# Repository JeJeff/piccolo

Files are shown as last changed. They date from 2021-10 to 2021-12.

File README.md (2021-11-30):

# Piccolo Macropads
These are mini macropads intended for video conference control.  Setup by default for Zoom, it could be used to Teams, Webex, or any other video conference system (or anything else) with keyboard shortcuts just by changing the keymapping.

The [Piccolo Macropad](https://github.com/JeJeff/piccolo/tree/main/piccolo) has 5 buttons, or 4 buttons and a rotary encoder, and an OLED screen.

The [Piccolo Mini Macropad](https://github.com/JeJeff/piccolo/tree/main/piccolo-mini) is the same but without the screen.

## Current Status
### Piccolo
The Piccolo has a working prototype, and revision 2 (including FR4 switch- and back-plates) is ready for ordering.

### Piccolo Mini
The Piccolo mini is designed not yet prototyped.  Work on this is paused until the bigger brother is ready for release.

## License
<br />The Piccolo Macropad and Piccolo Mini Macropad are licensed under a <a rel="license" href="http://creativecommons.org/licenses/by-sa/4.0/">Creative Commons Attribution-ShareAlike 4.0 International License</a>.

If you have built upon this work and have changed the design in a significant way, the non-commercial clause can be waived. If you have developed your own design using files in this repository and would like to sell it, please [create an issue](https://github.com/JeJeff/piccolo/issues/new/choose) to discuss it.

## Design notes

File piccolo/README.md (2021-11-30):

# Piccolo Macropad controller
Piccolo Macropad is intended for video conference control.  Setup by default for Zoom, it could be used to Teams, Webex, or anything else with keyboard shortcuts just by changing the keymapping.

## Key features
* 5 key macro pad
* Both 3 and 5 pin MX style switches supported
* Hot swap sockets
* OLED screen
* Optional rotary encoder replacing one of the keys
* QMK controlled
* Easy to solder

## Additional information
 * 2 layer PCB
 * Switchplate and backplate designs available
 * Both throughhole and SMD diodes supported
 
## Bill of materials
|Reference | Item | Quantity | Notes
|:---:|---|:---:|---
| | **Plates** | |
| | PCB | 1 |
| | Switchplate | 1 | 
| | Backplate | 1 | 
| | | |
| | **Components to solder** | |
| MX1-MX5  | Hotswap sockets | 4-5 | 
| ENC1 | EC11 Rotary Encoder | 0-1 | Optional, replaces MX5.
| D1-D5 | 1N4148 Diode | 5 | Both SMD (SOD-123) and through hole (DO-35) supported.
| U1 | Pro Micro | 1 | Or pin compatible controller.
| U1 | 12x1 male pin header | 2 | For the pro micro.
| OLED1 | 0.91" OLED screen | 1 | If you don't want the screen, consider using the [Piccolo Mini](https://github.com/JeJeff/piccolo/tree/main/piccolo-mini) instead.
| OLED1 | 4x1 male pin header | 1 | For the OLED screen.
| | | |
| | **Hardware** | |
| | M2 standoff 12mm | 3 | Max diameter 3.7mm, required when using back- and switch-plates.
| | M2 x 6mm flat head screw | 6 | Button head screws also work, could go as short as 4mm.
| | Rubber feet 8mm | 4 | 
| | | |
| | **Keys and Knobs** | |
| | MX Switches | 4-5 | 
| | Keycaps | 4-5 | Relegendable caps recommended, but the choice is yours
| | Encoder knob | 0-1 | Matching the encoder, max diameter 18mm

## License
<br />The Piccolo Macropad and Piccolo Mini Macropad are licensed under a <a rel="license" href="http://creativecommons.org/licenses/by-sa/4.0/">Creative Commons Attribution-ShareAlike 4.0 International License</a>.

If you have built upon this work and have changed the design in a significant way, the non-commercial clause can be waived. If you have developed your own design using files in this repository and would like to sell it, please [create an issue](https://github.com/JeJeff/piccolo/issues/new/choose) to discuss it.  I fully support those looking to make new things and be creative and will more than likely approve and support your project.

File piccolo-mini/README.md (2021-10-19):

# Piccolo Mini controller
Piccolo is a mini macropad intended for video conference control.  Setup by default for Zoom, it could be used to Teams, Webex, or any other video conference system with keyboard shortcuts just by changing the keymapping.  And of course you can repurpose it for anything else you feel like.
This is the little brother to the [Piccolo](https://github.com/JeJeff/piccolo) and does not have the OLED display.

## Key features
* 5 key macro pad
* Supports MX style switches
* Hot swap sockets
* Optional rotary encoder replacing one of the keys
* QMK controlled
* Easy to solder

## Additional information
 * 2 layer PCB
 * Switchplate and backplate designs available
 * Both throughhole and SMD diodes supported
 
## Bill of materials
|Reference | Item | Quantity | Notes
|---|---|---|---
| | PCB | 1 |
| | Switchplate | 1 | Technically optional, but recommended
| | Backplate | 1 | Technically optional, but recommended
| | M2 standoff 12mm | 3 | Max diameter 3.7mm, required when using back- and switch-plates
| | MX Switches | 4-5 | 
| | Keycaps | 4-5 | Relegendable caps recommended, but the choice is yours
| MX1-MX5  | Hotswap sockets | 4-5 | 1 per keyswitch
| ENC1 | EC11 Rotary Encoder | 0-1 | Optional, replaces MX5
| | Encoder knob | 0-1 | Matching the encoder, max diameter 18mm
| D1-D5 | 1N4148 Diode | 5 | Both SMD (SOD-123) and through hole (DO-35) supported
| U1 | Pro Micro | 1 | Or pin compatible controller

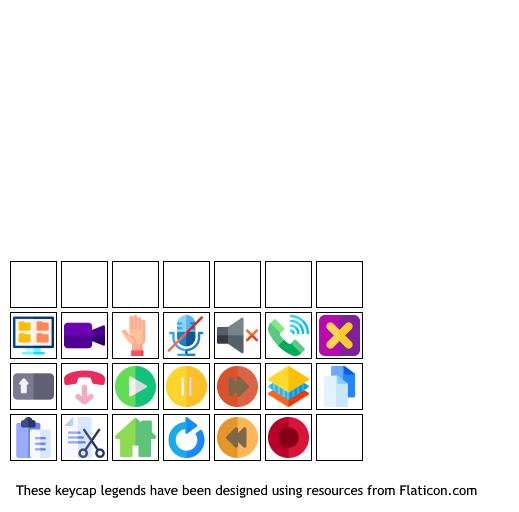
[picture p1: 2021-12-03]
piccolo/images/keycap_legends.png

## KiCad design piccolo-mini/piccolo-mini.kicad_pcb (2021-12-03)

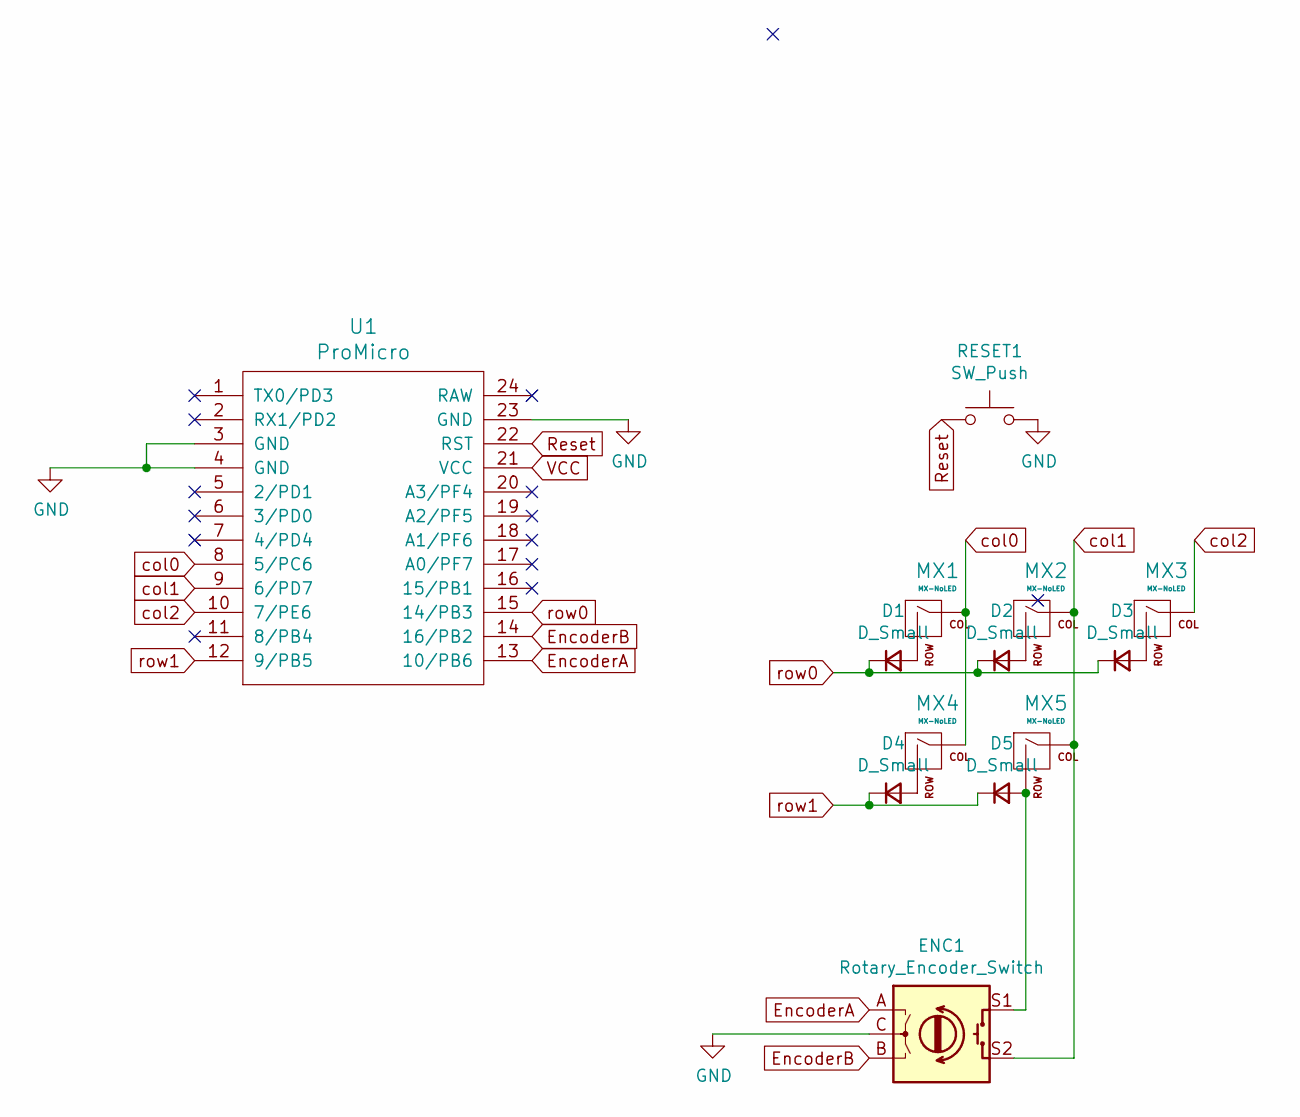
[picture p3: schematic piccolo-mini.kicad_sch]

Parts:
D1, D2, D3, D4, D5: D_Small; Diode-Hybrid-Back
ENC1: Rotary_Encoder_Switch; RotaryEncoder_EC11-no-legs
MX1, MX2, MX3, MX4, MX5: MX-NoLED; MXOnly-1U-Hotswap
RESET1: SW_Push; Reset_Jumper_Points
U1: ProMicro; ProMicro_face_out

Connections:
EncoderA: ENC1.A, U1.13 (10/PB6)
EncoderB: ENC1.B, U1.14 (16/PB2)
GND: ENC1.C, RESET1.2, U1.3 (GND), U1.4 (GND), U1.23 (GND)
unnamed: D1.2 (A), MX1.2 (ROW)
unnamed: D2.2 (A), MX2.2 (ROW)
unnamed: D3.2 (A), MX3.2 (ROW)
unnamed: D4.2 (A), MX4.2 (ROW)
unnamed: D5.2 (A), ENC1.S1, MX5.2 (ROW)
Reset: RESET1.1, U1.22 (RST)
VCC: U1.21 (VCC)
col0: MX1.1 (COL), MX4.1 (COL), U1.8 (5/PC6)
col1: ENC1.S2, MX2.1 (COL), MX5.1 (COL), U1.9 (6/PD7)
col2: MX3.1 (COL), U1.10 (7/PE6)
row0: D1.1 (K), D2.1 (K), D3.1 (K), U1.15 (14/PB3)
row1: D4.1 (K), D5.1 (K), U1.12 (9/PB5)

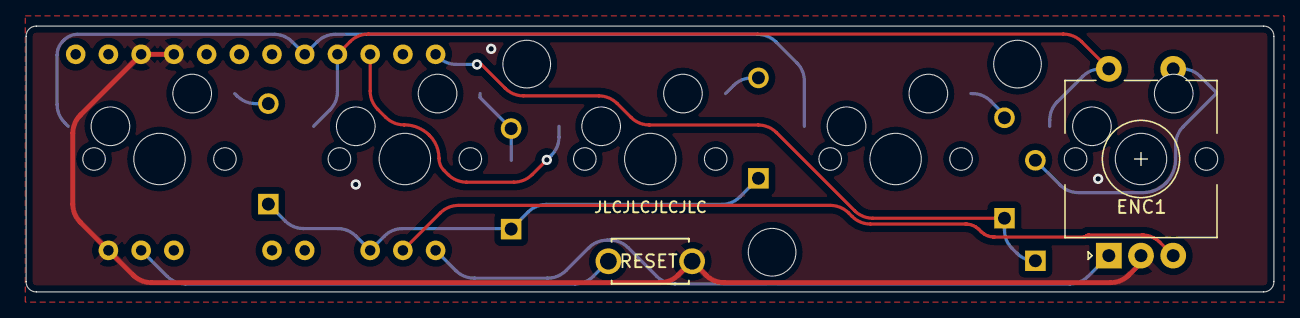
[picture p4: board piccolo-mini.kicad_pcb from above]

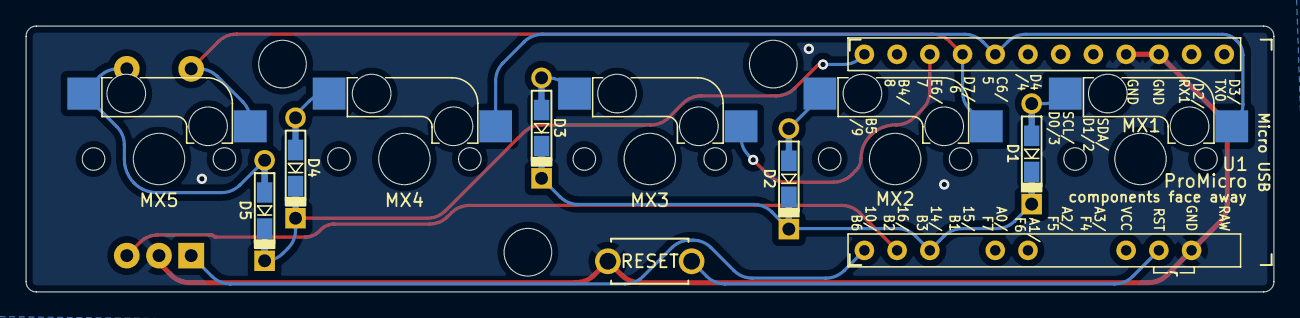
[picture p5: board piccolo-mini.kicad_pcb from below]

Board: 2 copper layers, 96.9 x 20.6 mm, 13 parts (2 on the bottom side), 14 nets.

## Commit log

2021-09-24 Add submodules
    [piccolo.kicad_pcb, piccolo.sch]
2021-09-24 Add libraries to kicad
2021-09-24 More kicad libs
2021-09-24 COmponents placed
    [piccolo.kicad_pcb, piccolo.sch]
2021-09-25 First prototype of piccolo ready for production
    [piccolo-B_Cu.gbl, piccolo-B_Mask.gbs, piccolo-B_Paste.gbp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]
2021-10-03 Sent for prototype
    [piccolo-B_Cu.gbl, piccolo-B_Mask.gbs, piccolo-B_Paste.gbp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]
2021-10-05 Continued tweaks
    [piccolo-mini.kicad_pcb, piccolo-mini.kicad_sch, piccolo.kicad_pcb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]
2021-10-16 flipped board, moved diodes
    [piccolo.kicad_sch]
2021-10-17 Added switchplate and backplate
    [piccolo-backplate.kicad_pcb, piccolo-backplate.kicad_sch, piccolo-switchplate.kicad_pcb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]
2021-10-17 Tidy folder structure, remove unwanted files
    [piccolo.sch]
2021-10-17 Logo added to backplate
    [piccolo-backplate.kicad_pcb]
2021-10-18 Sent switchplate to PCB manufacturer for first prototype.
    [piccolo-switchplate-B_Cu.gbl, piccolo-switchplate-B_Mask.gbs, piccolo-switchplate-B_Paste.gbp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]
2021-10-18 correct diode type in bom
2021-10-18 Update BOM
2021-10-19 backplate ready for prototype
    [piccolo-backplate-B_Cu.gbl, piccolo-backplate-B_Mask.gbs, piccolo-backplate-B_Paste.gbp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]
2021-10-22 Add PCB identifier and revision number
    [piccolo.kicad_pcb]
2021-10-22 Make PCB identifier a little fancier
    This might look terrible, we'll have to wait and see
    [piccolo.kicad_pcb]
2021-10-22 Tweak clearances
    [piccolo.kicad_pcb]
2021-10-22 Remove silk screen from PCB ID
    [piccolo.kicad_pcb]
2021-10-22 Big re-route on piccolo mini to get diodes onto the back and out of the way
    [piccolo-mini.kicad_pcb]
2021-10-22 Add identifiers to boards
    [piccolo-backplate.kicad_pcb, piccolo-mini.kicad_pcb, piccolo-switchplate.kicad_pcb]
2021-11-08 make oled cutout larger in switchplate. Prepare rev3 gerbers
    [piccolo-B_Cu.gbl, piccolo-B_Mask.gbs, piccolo-B_Paste.gbp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]
2021-11-09 rev0.1 pcb sent for prototype manufacturing
    [piccolo-mini-B_Cu.gbl, piccolo-mini-B_Mask.gbs, piccolo-mini-B_Paste.gbp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]
2021-11-09 add screws and feet to bom
2021-11-30 Made the oled cutout larger. because the pins interfere with the switchplate. Bump rev to 0.4
    [piccolo-backplate.kicad_pcb, piccolo-switchplate.kicad_pcb, piccolo.kicad_pcb]
2021-12-03 Remove a few pro micro pins that get in the way
    [piccolo-mini.kicad_pcb]
